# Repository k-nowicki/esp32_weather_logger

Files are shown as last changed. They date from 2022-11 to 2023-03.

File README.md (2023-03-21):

# Weather Station and logger based on ESP32

The Weather Station measures: Temperature, Humidity, Atm. Pressure and Solar exposure. It also keeps track of current date and time and take pictures. All of this data is logged on local storage (i.e. SD card). Main measurements are displayed in real time on the device OLED screen. All current and historical data can also be viewed by the web interface as well as fetched by API.
All user interactions are made by web interface. Besides display and on/off switch, the device has no other way to communicate with user.
The purpose of the device is to deliver historical weather informations along with pictures of those conditions, for further analysis.
Device can be used as weather conditions logger, time-lapse camera or just home weather station.

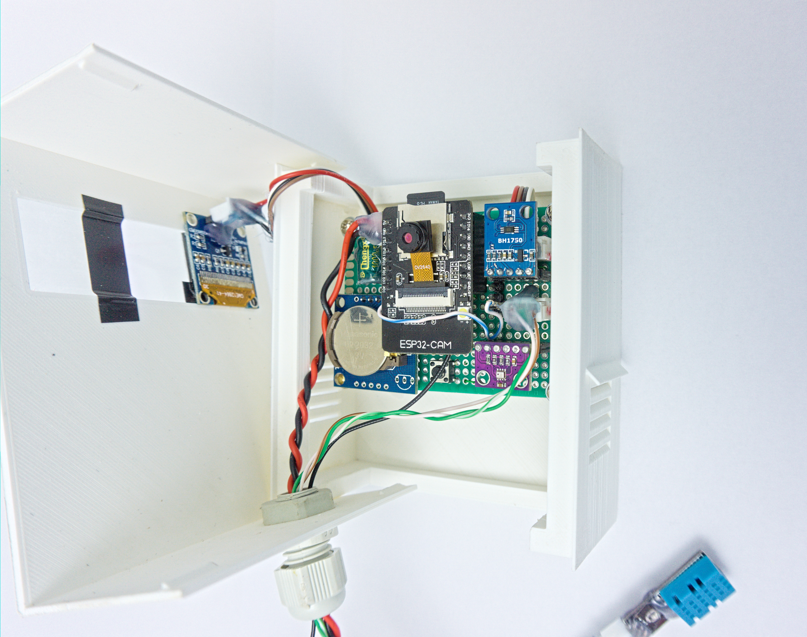
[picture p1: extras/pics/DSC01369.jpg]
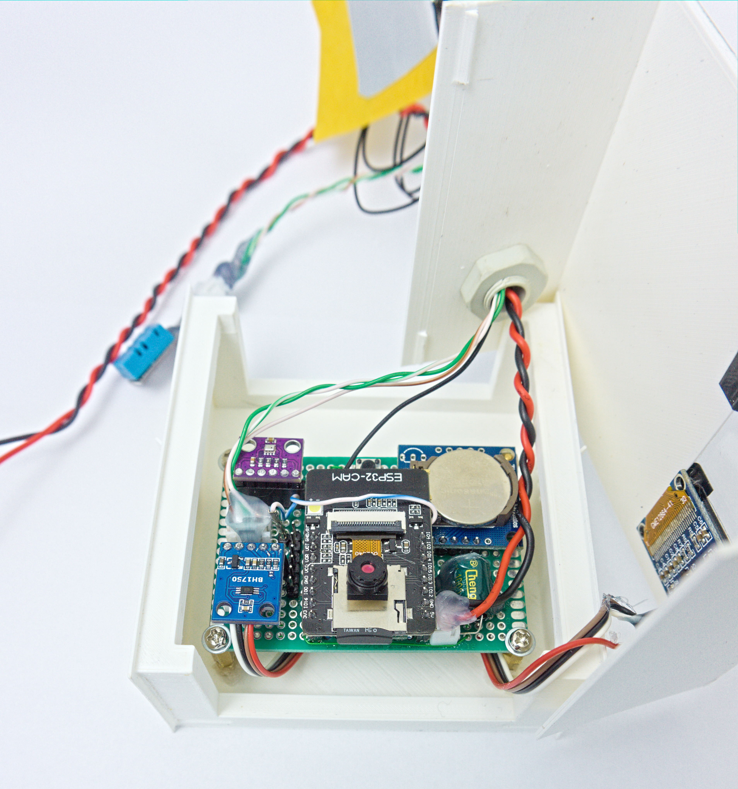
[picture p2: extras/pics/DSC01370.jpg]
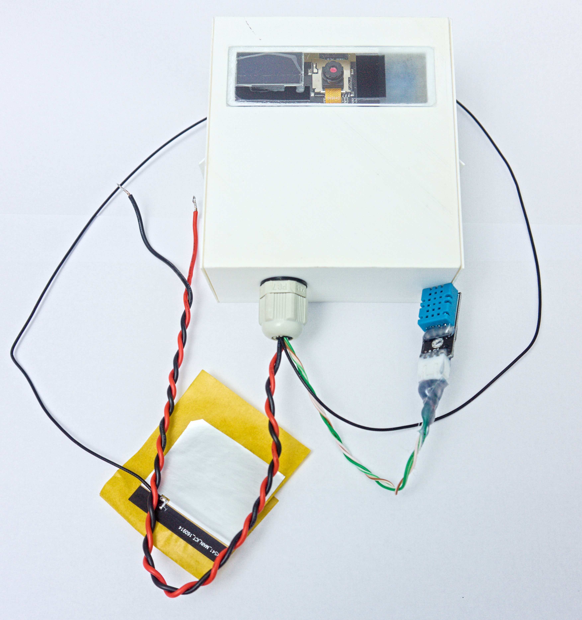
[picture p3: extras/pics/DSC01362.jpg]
  

## Hardware

|  Type | Name/Info  | Libs  |
| --- | --- | --- |
| MCU  | [ESP32-CAM](https://docs.platformio.org/en/latest/boards/espressif32/esp32cam.html)  | [ESP-IDF](https://github.com/espressif/esp-idf)  |
| Humidity/Temperature (VAR 1) | [DHT11](http://gotronik.pl/img/dht11.pdf) | [Anacron-mb/esp32-DHT11](https://github.com/Anacron-mb/esp32-DHT11)  |
| Humidity/Temperature (VAR 2) | [HTU21](https://cdn-shop.adafruit.com/datasheets/1899_HTU21D.pdf) | [Adafruit_HTU21DF](https://github.com/adafruit/Adafruit_HTU21DF_Library)  |
| Pressure/Temperature  |[BMP280](https://www.bosch-sensortec.com/products/environmental-sensors/pressure-sensors/bmp280/)| [Adafruit_BMP280_Library](https://github.com/adafruit/Adafruit_BMP280_Library); [Adafruit_Sensor](https://github.com/adafruit/Adafruit_Sensor); [Adafruit_BusIO](https://github.com/adafruit/Adafruit_BusIO); [arduino-esp32](https://github.com/espressif/arduino-esp32) |
|Light |[BH1750](https://www.handsontec.com/dataspecs/sensor/BH1750%20Light%20Sensor.pdf) |  [claws/BH1750](https://github.com/claws/BH1750); [arduino-esp32](https://github.com/espressif/arduino-esp32)  |
|Wind |[KK-ANEMO]() |  [KK-ANEMO]()|
|OLED |[GME12864-41/ SSD1306](https://nettigo.pl/products/wyswietlacz-oled-0-96-i2c-128x64-ssd1306-bialy) \| [Reserve info](https://datasheethub.com/ssd1306-128x64-mono-0-96-inch-i2c-oled-display/) |[Adafruit_SSD1306](https://github.com/adafruit/Adafruit_SSD1306); [Adafruit-GFX-Library](https://github.com/adafruit/Adafruit-GFX-Library); [arduino-esp32](https://github.com/espressif/arduino-esp32) |
RTC (Var 1)| [HW084 / DS3231](http://www.szhwmake.com/prod_view.aspx?TypeId=83&Id=350&FId=t3:83:3) \| [Reserve info](https://lastminuteengineers.com/ds3231-rtc-arduino-tutorial/) |[ErriezDS3231 (modified)](https://github.com/k-nowicki/ErriezDS3231)|
RTC (Var 2)| [TinyRTC / DS1307](https://www.analog.com/media/en/technical-documentation/data-sheets/DS1307.pdf) \| [Reserve info](https://lastminuteengineers.com/ds1307-rtc-arduino-tutorial/) | [ErriezDS1307 (modified)](https://github.com/Erriez/ErriezDS1307)|
| SD Card  | Any standard SDSC/SDHC/SDXC Card<br/>(preffered at least 8GB for picture storage)  | [ESP-IDF](https://github.com/espressif/esp-idf)  |

## Connections
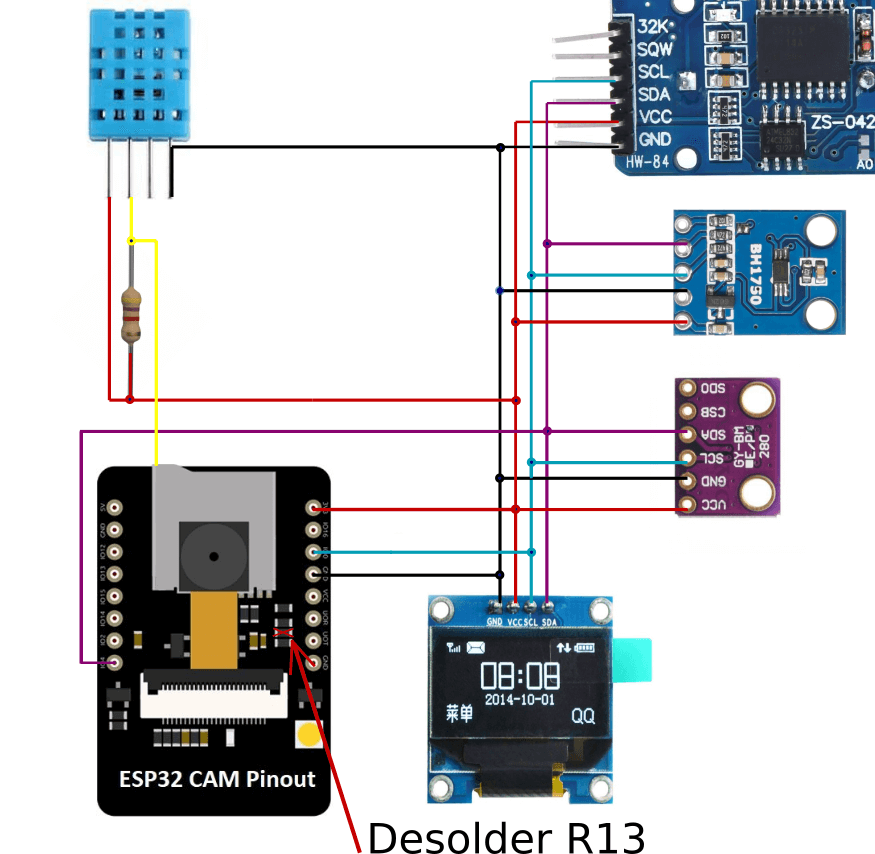
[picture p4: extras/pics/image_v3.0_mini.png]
Wiring diagram


R13 resistor needs to be desoldered (**)

DHT11 sensor needs to be soldered to GPIO33 which is hardwired to onboard LED (*)

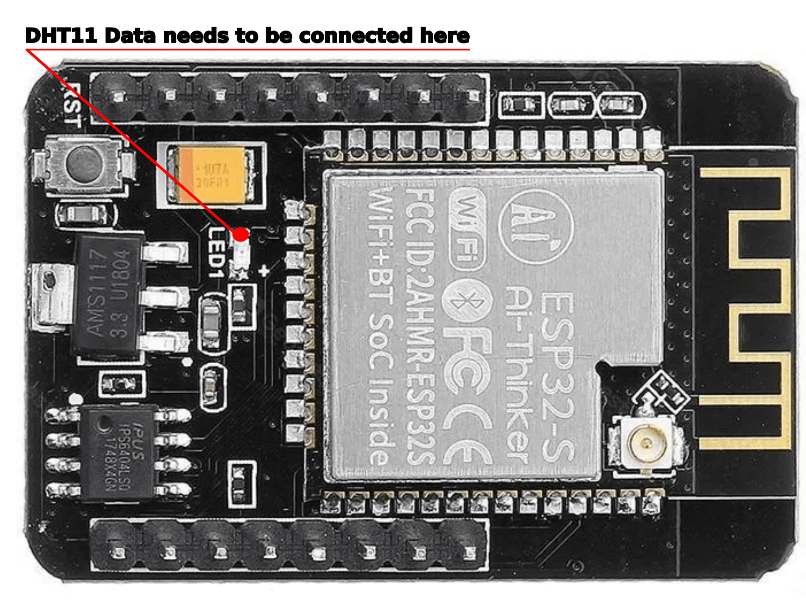
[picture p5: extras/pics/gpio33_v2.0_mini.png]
GPIO33


Warning! On the schematic above SCL and SDA are swapped, you need to change definitions in setup.h or connect them the other way round.

## Environment requirements
This project needs ESP-IDF environment installed on development machine (developed on ESP-IDF v4.4.3).
[Follow the instructions](https://docs.espressif.com/projects/esp-idf/en/v4.4.3/esp32/get-started/index.html "ESP-IDF Framework") to install all necessary software. After installing check your setup first with one of the ESP-IDF examples.

## How to flash your ESP32
Instructions on how to connect and flash esp32 can be found also on [espressif docs](https://docs.espressif.com/projects/esp-idf/en/v3.3.5/get-started-cmake/index.html#step-9-flash-to-a-device "espressiff docs").

## Project status: under development
 
 What is implemented:
  - OLED Display displays current measurements, date, time and IP address
  - Sensors: pressure, temperature from two sensors, humidity, light and wind***
  - External and internal RTCs with periodic NTP time sync
  - WiFi connectivity (with credentials configured by menuconfig)
  - SD card with file system
  - Logging of measurements in json and CSV formatted logs in two densities (1/min -averaged and 1/sec)
  - HTTPS server (serves files from SD and responds to API calls)
  - Camera takes pictures every 5sec. Current picture is displayed on index web page below measurements.
  - Every 5 minutes new picture is saved to SD card
  - Web application for displaying measurements, pictures and logs (with https)
  
  *) DHT11 sensor if used, needs to be connected to GPIO33 which on the board is not connected to any external I/O pin. Instead Adafruit designed the board so that the GPIO33 (which unlike any other available pin has no second function) is connected exclusively to on board LED.

**) I2C_SCL needs to be defined as GPIO4 (There is no other free IO that can be used as I2C signal). But for it to work there is another small hack needed. R13 resistor needs to be desoldered from esp32-cam board. If R13 is not removed, the FLASH_LED driver forces GPIO4 to be max 0.7V and I2C bus will not work.

***) Wind anemometer (KK-ANEMO) connected to I2C bus is also under development. Project will be published soon as open source.

## Assembly and getting ready
Once you have all modules and parts needed as well as software installed:
 - prepare the esp32 board and connect all as shown on the schematic above
 - copy *www* directory with its content to root dir of SD card
 - use menuconfig ( <code>idf.py menuconfig</code> from project root dir) to set:
  - WiFi credentials [KK_Connection_Configuration]
  - RTC type [KK_RTC_Configuration]
 - use setup.h to verify/set:
  - I2C_SDA and I2C_SCL to be consistent with actual connections
  - uncomment definition of used external sensor: <code>EXTERNAL_SENSOR_DHT11</code> or <code>EXTERNAL_SENSOR_HTU21</code>
 - compile the code <code>idf.py build</code>
 - connect the esp32 board to USB and enter flash mode (pull-down GPIO0 and press RESET button)
 - upload flash content and run serial monitor <code>idf.py -p \<COM_PORT> flash monitor</code>  
Replace <code>\<COM_PORT></code> with that in your setup, for example COM4 on Windows or /dev/ttyUSB0 on Linux.
 - after flashing reset your board again, with GPIO0 disconnected from ground this time

If everything done correctly, you should see immediately debug output on the serial monitor.
After several seconds there should be all measurements, date, time and IP address of the station visible on the display.
You can now use this IP to open device web page. Remember that only https protocol works, put <code>https://</code> before IP in your browser! 
It may be also necessary to confirm unsafe access in the browser, as device has no proper third-party certificate installed.

## Housing
As a weather station the device needs to be directly exposed to weather conditions.
I designed enclosure for 3d printing. Files in stl format can be found in extras/case.
Enclosure is designed with 25,4mm x 76,2mm glass window that utilizes standard 1x3 inch microscope slides. 
The best slides are one side matted which works as diffuser for light sensor.

## Web Interface
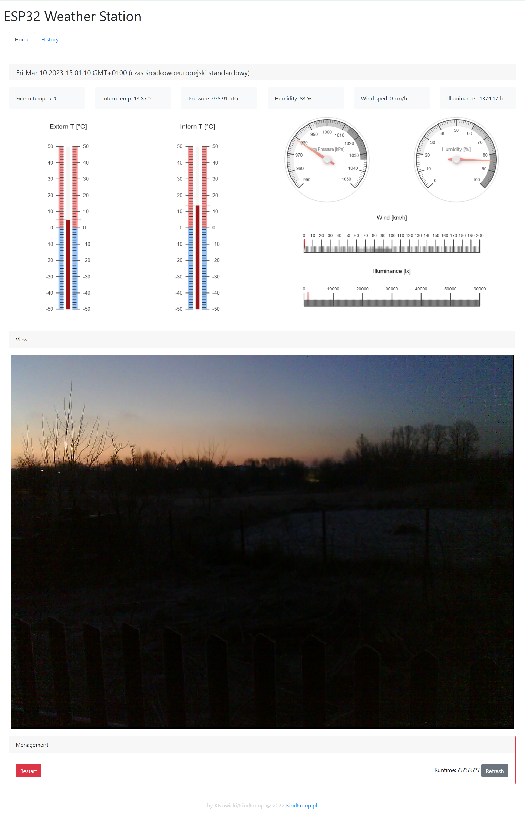
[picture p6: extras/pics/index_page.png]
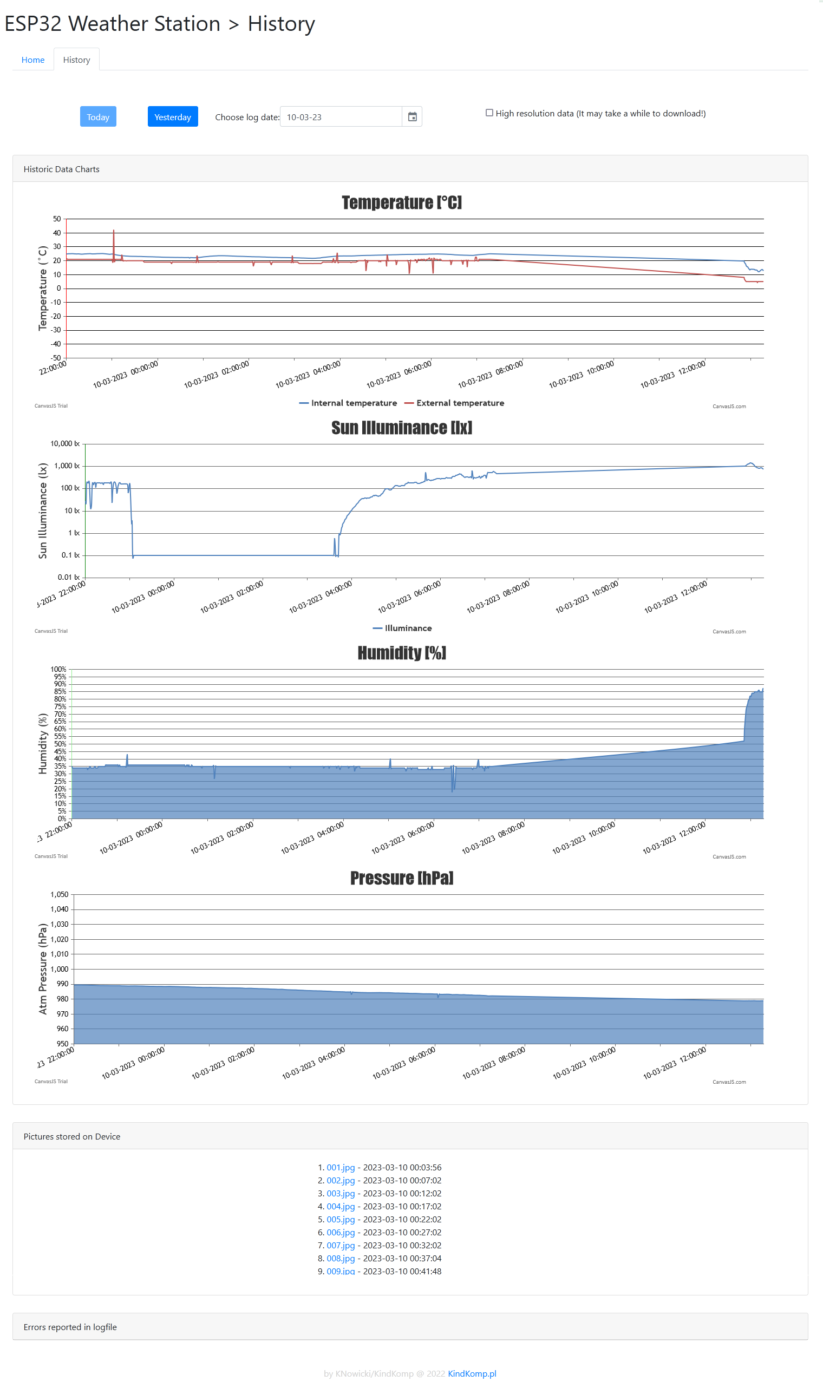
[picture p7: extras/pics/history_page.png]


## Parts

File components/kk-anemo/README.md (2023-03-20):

# KK-ANEMO

## Overview

The KK-Anemometer is a DIY cup-anemometer based on popular A/Y3144 Hall effect 
switch. The Switch is connected to LPC1114 uC, which counts interrupts and measures
wind speed based on that. Communication with that uC is done by I2C bus.
Protocol is extremely simple - send address of the device (0x56) and receive
2-bytes of data. Higher byte is the integer part and lower byte is a fractional 
part. Lower byte needs to be divided by 256 and then added to the integer part to
make whole float value (example below).

<code>
    h_value = __wire_read(); <br/>
    l_value = __wire_read(); <br/>
    velocity = h_value + (float)((l_value*1000)/256)/1000; <br/>
</code>

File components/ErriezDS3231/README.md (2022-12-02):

# DS3231 high precision I2C RTC library for Arduino



This is a DS3231 high precision I2C RTC library for Arduino.

DS3231

## Library features

* libc `<time.h>` compatible
* Read/write date/time `struct tm`
* Set/get Unix epoch UTC `time_t`
* Set/get time (hour, min, sec)
* Set/get date and time (hour, min, sec, mday, mon, year, wday)
* Read temperature (0.25 degree resolution)
* Alarm 1 (second/minute/hour/day/date match) 
* Alarm 2 (minute/hour/day/date match)
* Polling and Alarm `INT/SQW` interrupt pin
* Control `32kHz` out signal (enable/disable)
* Control `SQW` signal (disable / 1 / 1024 / 4096 / 8192Hz)
* Configure aging offset
* Serial terminal interface
* Full RTC register access
* Set date/time over serial with Python script

## Hardware

Any Arduino hardware with a TWI interface and `Wire.h` support.

DS3231 - Arduino UNO

### ESP32 notes

**ESP32 problem:** The Arduino IDE | Board manager installs an old version ```1.0.0``` from `https://dl.espressif.com/dl/package_esp32_index.json` which contains a broken I2C repeated start. Generating a repeated start with ```Wire.endTransmission(false);``` results in reading zero's from any I2C device and is not a problem of this library.

**Solution:** Use the Git master branch (or a newer release when available) to solve this problem as described on:
https://github.com/espressif/arduino-esp32/blob/master/docs/arduino-ide/windows.md.

## Pins

| Pins board - DS3231 | VCC  | GND  | SDA | SCL | SQW |
| --- | :--: | :--: | :---: | :---: | :---: |
| Arduino UNO (ATMega328 boards) |  5V  | GND  | A4 | A5 | D2 (INT0)  |
| Arduino Mega2560 |  5V  | GND  | D20 | D21 | D2 (INT4)  |
| Arduino Leonardo |  5V  | GND  | D2 | D3 | D7 (INT6)  |
| Arduino DUE (ATSAM3X8E) | 3V3  | GND  | 20 | 21 | 2 |
| ESP8266 | 3V3  | GND  | GPIO4 (D2) | GPIO5 (D1) | GPIO0 (D3) |
| ESP32 | 3V3  | GND  | GPIO21 | GPIO22 | GPIO0 |

Note: Tested ESP8266 / ESP32 boards:

* **ESP8266 boards**: ESP12F / WeMos D1 & R2 / Node MCU v2 / v3
* **ESP32 boards:** WeMos LOLIN32 / LOLIN D32

Other unlisted MCU's may work, but are not tested.

## Examples

Arduino IDE | Examples | Erriez DS3231 RTC:

* [AgingOffset](https://github.com/Erriez/ErriezDS3231/blob/master/examples/ErriezDS3231AgingOffset/ErriezDS3231AgingOffset.ino) Aging offset programming
* [AlarmInterrupt](https://github.com/Erriez/ErriezDS3231/blob/master/examples/ErriezDS3231AlarmInterrupt/ErriezDS3231AlarmInterrupt.ino) Alarm with interrupts
* [AlarmPolling](https://github.com/Erriez/ErriezDS3231/blob/master/examples/ErriezDS3231AlarmPolling/ErriezDS3231AlarmPolling.ino) Alarm polled
* [DumpRegisters](https://github.com/Erriez/ErriezDS3231/blob/master/examples/ErriezDS3231DumpRegisters/ErriezDS3231DumpRegisters.ino) Dump registers polled
* [SetBuildDateTime](https://github.com/Erriez/ErriezDS3231/blob/master/examples/ErriezDS3231SetBuildDateTime/ErriezDS3231SetBuildDateTime.ino) Set build date/time
* [SetGetDateTime](https://github.com/Erriez/ErriezDS3231/blob/master/examples/ErriezDS3231SetGetDateTime/ErriezDS3231SetGetDateTime.ino) Simple RTC read date/time example
* [SetGetTime](https://github.com/Erriez/ErriezDS3231/blob/master/examples/ErriezDS3231SetGetTime/ErriezDS3231SetGetTime.ino)  Set/Get time
* [SQWInterrupt](https://github.com/Erriez/ErriezDS3231/blob/master/examples/ErriezDS3231SQWInterrupt/ErriezDS3231SQWInterrupt.ino)  Blink LED on SQW interrupt pin
* [Temperature](https://github.com/Erriez/ErriezDS3231/blob/master/examples/ErriezDS3231Temperature/ErriezDS3231Temperature.ino) Temperature
* [Terminal](https://github.com/Erriez/ErriezDS3231/blob/master/examples/ErriezDS3231Terminal/ErriezDS3231Terminal.ino) Advanced terminal interface with [set date/time Python](https://github.com/Erriez/ErriezDS3231/blob/master/examples/ErriezDS3231Terminal/ErriezDS3231Terminal.py) script
* [Test](https://github.com/Erriez/ErriezDS3231/blob/master/examples/ErriezDS3231Test/ErriezDS3231Test.ino) Regression test
* [WriteRead](https://github.com/Erriez/ErriezDS3231/blob/master/examples/ErriezDS3231WriteRead/ErriezDS3231WriteRead.ino) Write/read `struct tm`

## Documentation

- [Doxygen online HTML](https://erriez.github.io/ErriezDS3231) 
- [Doxygen PDF](https://github.com/Erriez/ErriezDS3231/blob/master/ErriezDS3231.pdf)
- [DS3231 datasheet](https://github.com/Erriez/ErriezDS3231/blob/master/extras/DS3231.pdf)

## Usage

**Initialization**

```c++
#include <Wire.h>
#include <ErriezDS3231.h>

// Create RTC object
ErriezDS3231 rtc;

void setup()
{
    // Initialize TWI with a 100kHz (default) or 400kHz clock
    Wire.begin();
    Wire.setClock(400000);
    
    // Initialize RTC
    while (!rtc.begin()) {
        // Error: Could not detect DS3231 RTC, retry after some time
        delay(3000);
    }
}
```

**Alternative Initialization**

If your platform has more than one I2C buses, You can pass pointer to particular Wire interface to intializer as in example below:

```c++
#include <Wire.h>
#include <ErriezDS3231.h>

// Create RTC object
ErriezDS3231 rtc;

void setup()
{
    // Initialize TWI with a 100kHz (default) or 400kHz clock
    Wire1.begin();
    Wire1.setClock(400000);
    
    // Initialize RTC
    while (!rtc.begin(&Wire1)) {
        // Error: Could not detect DS3231 RTC, retry after some time
        delay(3000);
    }
}
```

**Check oscillator status at startup**

```c++
// Check oscillator status
if (rtc.isOscillatorStopped()) {
    // Error: RTC oscillator stopped. Date/time cannot be trusted. 
    // Set new date/time before reading date/time.

    // Enable oscillator
    rtc.clockEnable(true);
}
```

**Set time**

```c++
// Write time to RTC
if (!rtc.setTime(12, 0, 0)) {
    // Error: Set time failed
}
```

**Get time**

```c++
uint8_t hour;
uint8_t minute;
uint8_t second;

// Read time from RTC
if (!rtc.getTime(&hour, &minute, &second)) {
    // Error: RTC read failed
}
```

**Set date and time**

```c++
// Write RTC date/time: 13:45:09  31 December 2019  0=Sunday, 2=Tuesday
if (!rtc.setDateTime(13, 45, 9,  31, 12, 2019,  2) {
    // Error: RTC write failed
}
```

**Get date and time**

```c++
uint8_t hour;
uint8_t min;
uint8_t sec;
uint8_t mday;
uint8_t mon;
uint16_t year;
uint8_t wday;

// Read RTC date/time
if (!rtc.getDateTime(&hour, &min, &sec, &mday, &mon, &year, &wday) {
    // Error: RTC read failed
}

// hour: 0..23
// min: 0..59
// sec: 0..59
// mday: 1..31
// mon: 1..12
// year: 2000..2099
// wday: 0..6 (0=Sunday .. 6=Saturday)
```

**Write date/time struct tm**

```c++
struct tm dt;

dt.tm_hour = 12;
dt.tm_min = 34;
dt.tm_sec = 56;
dt.tm_mday = 29;
dt.tm_mon = 1; // 0=January
dt.tm_year = 2020-1900;
dt.tm_wday = 6; // 0=Sunday

if (!rtc.write(&dt)) {
    // Error: RTC Read failed
}
```

**Read date/time struct tm**

```c++
struct tm dt;

// Read RTC date/time
if (!rtc.read(&dt)) {
    // Error: RTC read failed
}
```

**Read Unix Epoch UTC**

```c++
time_t t;

// Read Unix epoch UTC from RTC
if (!rtc.getEpoch(&t)) {
    // Error: RTC read failed
}
```

**Write Unix Epoch UTC**

```c++
// Write Unix epoch UTC to RTC
if (!rtc.setEpoch(1599416430UL)) {
    // Error: Set epoch failed
}
```

**Get temperature**

```c++
int8_t temperature = 0;
uint8_t fraction = 0;

// Force temperature conversion
// Without this call, it takes 64 seconds before the temperature is updated.
if (!rtc.startTemperatureConversion()) {
    // Error: Start temperature conversion failed 
}

// Read temperature
if (!rtc.getTemperature(&temperature, &fraction)) {
    // Error: Get temperature failed
}

// Print temperature. The output below is for example: 28.25C
Serial.print(temperature);
Serial.print(F("."));
Serial.print(fraction);
Serial.println(F("C"));
```

**Program Alarm 1**

Note: Alarm 1 and Alarm 2 have different behavior. Please refer to the documentation which ```Alarm1Type``` and ```Alarm2Type``` are supported. Some examples:

```c++
// Generate alarm 1 every second
rtc.setAlarm1(Alarm1EverySecond, 0, 0, 0, 0);

// Generate alarm 1 every minute and second match
rtc.setAlarm1(Alarm1EverySecond, 0, 0, 45, 30);

// Generate alarm 1 every day, hour, minute and second match
rtc.setAlarm1(Alarm1MatchDay, 
              1,  // Alarm day match (1 = Monday)
              12, // Alarm hour match
              45, // Alarm minute match
              30  // Alarm second match
);
```

**Program Alarm 2**

```c++
// Generate alarm 2 every minute
rtc.setAlarm2(Alarm2EveryMinute, 0, 0, 0);

// Generate alarm 2 every hour, minute match
rtc.setAlarm2(Alarm2MatchHours, 0, 23, 59);

// Generate alarm 2 every date, hour, minute match
rtc.setAlarm2(Alarm2MatchDate, 28, 7, 0);
```

**Alarm polling**

Note: The ```INT``` pin changes to low when an Alarm 1 or Alarm 2 match occurs and and the interrupt is enabled. The pin remains low until both alarm flags are cleared by the application.

```c++
// Poll alarm 1 flag
if (rtc.getAlarmFlag(Alarm1)) {
    // Handle Alarm 1
    
    // Clear alarm 1 flag
	rtc.clearAlarmFlag(Alarm1);
}

// Poll alarm 2 flag
if (rtc.getAlarmFlag(Alarm2)) {
    // Handle Alarm 2
    
    // Clear alarm 2 flag
	rtc.clearAlarmFlag(Alarm2);
}
```

**Alarm interrupt**

Note: Enabling interrupt will disable the ```SQW``` output signal.

```c++
// Uno, Nano, Mini, other 328-based: pin D2 (INT0) or D3 (INT1)
#define INT_PIN     2

// Alarm interrupt flag must be volatile
volatile bool alarmInterrupt = false;

#if defined(ARDUINO_ARCH_ESP8266) || defined(ARDUINO_ARCH_ESP32)
ICACHE_RAM_ATTR
#endif
void alarmHandler()
{
    // Set global interrupt flag
    alarmInterrupt = true;
}

void setup()
{
    ...

    // Attach to INT0 interrupt falling edge
    pinMode(INT_PIN, INPUT_PULLUP);
    attachInterrupt(digitalPinToInterrupt(INT_PIN), alarmHandler, FALLING);
    
    // Enable Alarm 1 and 2 interrupts
    rtc.alarmInterruptEnable(Alarm1, true);
    rtc.alarmInterruptEnable(Alarm2, true);
}

void loop()
{
    // Check global alarm interrupt flag
    if (alarmInterrupt) {
        if (rtc.getAlarmFlag(Alarm1)) {
            // Handle alarm 1
            
            // Clear alarm 1 interrupt
            rtc.clearAlarmFlag(Alarm1);
        }
        
        if (rtc.getAlarmFlag(Alarm2)) {
            // Handle alarm 2
            
            // Clear alarm 2 interrupt
            rtc.clearAlarmFlag(Alarm2);
        }
    }
}
```

**32kHz clock out**

Enable or disable ```32kHz``` output pin.

```c++
rtc.outputClockPinEnable(true);  // Enable 
rtc.outputClockPinEnable(false);	// Disable
```

**Square Wave Out (SQW)**

Note: Enabling ```SQW``` pin will disable the alarm ```INT``` signal.

```c++
rtc.setSquareWave(SquareWaveDisable);	// Disable
rtc.setSquareWave(SquareWave1Hz);		// 1Hz
rtc.setSquareWave(SquareWave1024Hz);	// 1024Hz
rtc.setSquareWave(SquareWave4096Hz);	// 4096Hz
rtc.setSquareWave(SquareWave8192Hz);	// 8192Hz
```

## API changes v1.0.1 to v2.0.0

The API has been changed to make RTC libraries compatible with libc `time.h`. This makes it easier
to calculate with date/time and port the application to different platforms. See changes below:

| v1.0.1 | v2.0.0 |
| --- | --- |
| `DS3231_DateTime` | `struct tm` |
| Function returns `true`: failure | Function returns `false`: failure |
| | `clearOscillatorStopFlag()` merged into `oscillatorEnable()` |
| `setDateTime()` | `bool write(struct tm *dt)` |
| `getDateTime()` | `bool read(struct tm *dt)` |
| `getEpochTime()` | `time_t getEpoch()` |
| | `bool setEpoch(time_t t)` |
| | `void setDateTime(uint8_t hour, uint8_t min, uint8_t sec, uint8_t mday, uint8_t mon, uint16_t year, uint8_t wday)` |
| | `void getDateTime(uint8_t *hour, uint8_t *min, uint8_t *sec, uint8_t *mday, uint8_t *mon, uint16_t *year, uint8_t *wday)` |
| `ErriezDS3231Debug` | class removed to reduce flash size |

## Library dependencies

* `Wire.h`
* `Terminal.ino` requires `ErriezSerialTerminal` library.

## Library installation

Please refer to the [Wiki](https://github.com/Erriez/ErriezArduinoLibraries/wiki) page.

## More Arduino Libraries from Erriez

* [Erriez Libraries](https://github.com/Erriez/ErriezArduinoLibraries)

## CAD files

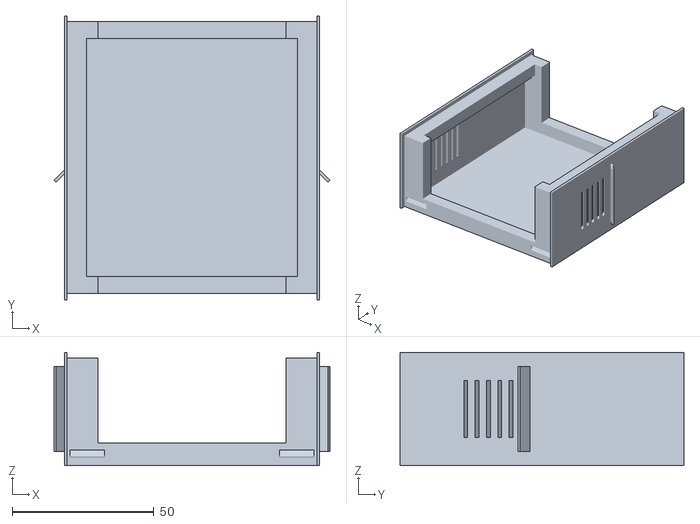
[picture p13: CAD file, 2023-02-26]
extras/case/Base.stl
97.3 x 100.0 x 40.0

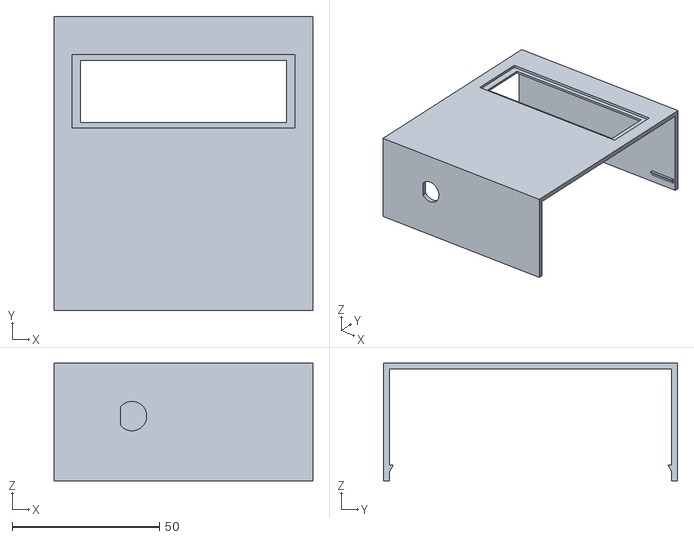
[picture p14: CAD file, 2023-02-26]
extras/case/TopCover.stl
88.0 x 100.0 x 40.0

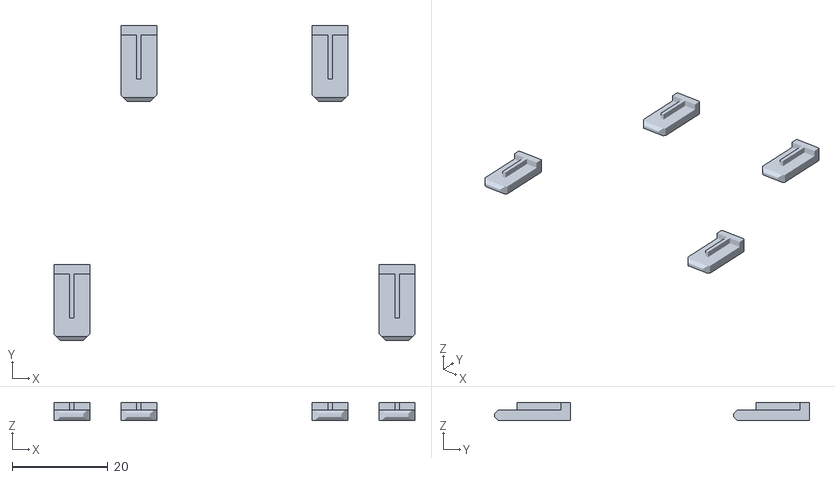
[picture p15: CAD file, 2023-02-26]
extras/case/Mount.stl
75.5 x 66.0 x 3.80

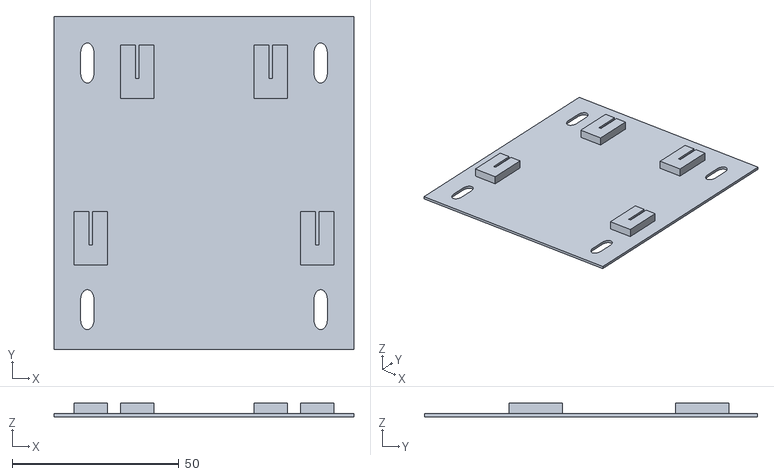
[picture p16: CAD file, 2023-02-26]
extras/case/MountPlate.stl
90.0 x 100.0 x 4.25

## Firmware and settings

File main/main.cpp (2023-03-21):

/* KK Weather Station
 *
 * Platform: ESP32 (Tested on ESP32-CAM Development Board)
 * See project documentation for more detailed description.
 *
 *  Copyright (c) <2022> <Karol Nowicki>
 *
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
 *  THE SOFTWARE IS PROVIDED "AS IS", WITHOUT WARRANTY OF ANY KIND, EXPRESS OR
 *  IMPLIED, INCLUDING BUT NOT LIMITED TO THE WARRANTIES OF MERCHANTABILITY,
 *  FITNESS FOR A PARTICULAR PURPOSE AND NONINFRINGEMENT. IN NO EVENT SHALL THE
 *  AUTHORS OR COPYRIGHT HOLDERS BE LIABLE FOR ANY CLAIM, DAMAGES OR OTHER
 *  LIABILITY, WHETHER IN AN ACTION OF CONTRACT, TORT OR OTHERWISE, ARISING FROM,
 *  OUT OF OR IN CONNECTION WITH THE SOFTWARE OR THE USE OR OTHER DEALINGS IN THE
 *  SOFTWARE.
*/

//System
#include <stdio.h>
#include <stdlib.h>
#include <string.h>
#include <sys/unistd.h>
#include <sys/stat.h>
#include "freertos/FreeRTOS.h"
#include "freertos/task.h"
#include "freertos/semphr.h"
#include <Wire.h>
#include "esp_system.h"
#include "esp_log.h"
#include "esp_err.h"
#include "esp_event.h"
#include "esp_attr.h"
#include "esp_sleep.h"
#include "esp_sntp.h"
#include <time.h>
#include "nvs_flash.h"
#include "esp_vfs_fat.h"
#include "sdmmc_cmd.h"
#include "driver/sdmmc_host.h"
#include <protocol_common.h>
#include <k_math.h>

//App
#include "setup.h"
#include "tasks/tasks.h"
#include "app.h"
#include "kk_http_app/src/kk_http_app.h"
#include "kk_http_app/src/kk_http_server_setup.h"
#include "camera_helper.h"

extern "C" {
  void app_main(void);
}



/*******************************************************************************
 * Variable definitions
 */

//Business logic global variables
measurement g_curr_measures; // Current measurements

// RTC object depending on used physical device
#ifdef CONFIG_RTC_DS1307
ErriezDS1307 g_rtc;
#elif CONFIG_RTC_DS3231
ErriezDS3231 g_rtc;
#endif

//Sensor global objects
BH1750 g_lightMeter(BH1750_ADDR);
ANEMO g_windMeter(ANEMO_ADDR);
Adafruit_BMP280 g_pressureMeter(&Wire1); // I2C
Adafruit_SSD1306 g_display(SCREEN_WIDTH, SCREEN_HEIGHT, &Wire1, OLED_RESET);
#ifdef EXTERNAL_SENSOR_HTU21
Adafruit_HTU21DF g_htu21 = Adafruit_HTU21DF();
#endif

//SD Card global object
sdmmc_card_t * g_card;

//semaphores
SemaphoreHandle_t g_current_measuers_mutex;
SemaphoreHandle_t g_uart_mutex;
SemaphoreHandle_t g_card_mutex;

//task handlers
TaskHandle_t g_vRTCTaskHandle = NULL;
TaskHandle_t g_vDHT11TaskHandle = NULL;
TaskHandle_t g_vSensorsTaskHandle = NULL;
TaskHandle_t g_vDisplayTaskHandle = NULL;
TaskHandle_t g_vCameraTaskHandle = NULL;
TaskHandle_t g_vSDCSVLGTaskHandle = NULL;
TaskHandle_t g_vSDAVGLGTaskHandle = NULL;
TaskHandle_t g_vSDJSLGTaskHandle = NULL;
TaskHandle_t g_vStatsTaskHandle = NULL;

/*******************************************************************************
 *  App Main
 */
void app_main(void){
  const char* TAG = "app_setup";
  //create semaphores
  g_current_measuers_mutex = xSemaphoreCreateMutex();
  g_uart_mutex = xSemaphoreCreateMutex();
  g_card_mutex = xSemaphoreCreateMutex();
  if(g_uart_mutex == NULL){
      ESP_LOGE(TAG, "UART Mutex creation failed! Hold till reset!");
      for(;;);
  }

  //initArduino();
  //Allow other core to finish initialization
  vTaskDelay(pdMS_TO_TICKS(10));

  //Setup Camera
  if(init_camera(FRAMESIZE) != ESP_OK){
    ESP_LOGE(TAG, "Camera initialization failed!");
//    for(;;); // Don't proceed, loop forever
  }else{
    ESP_LOGI(TAG, "Camera initialized.");
  }

  //Set I2C interface
  Wire1.begin(I2C_SDA, I2C_SCL);
  Wire1.setClock(400000);

  //Setup OLED display
  if(!g_display.begin(SSD1306_SWITCHCAPVCC, OLED_ADDR)) {
    g_display.display();
    ESP_LOGE(TAG, "SSD1306 allocation failed");
  }else{
    ESP_LOGI(TAG, "SSD1306 OLED Display initialized.");
    init_app_screen();
  }

  //search_i2c(); // search for I2C devices (helpful if any uncertainty about sensor addresses raised)

  //Set GPIOS for DHT11 and DS18B20 as GPIOs
  ESP_LOGI(TAG, "GPIO's configuration...");
  PIN_FUNC_SELECT(GPIO_PIN_MUX_REG[GPIO_DHT11], PIN_FUNC_GPIO);
  PIN_FUNC_SELECT(GPIO_PIN_MUX_REG[GPIO_DS18B20], PIN_FUNC_GPIO);
  //Set up DHT11 GPIO
  DHT11_init(GPIO_DHT11);
  ESP_LOGI(TAG, "GPIO's initialized!");


  //BH1750 Initialization
  if(!g_lightMeter.begin(BH1750::Mode::CONTINUOUS_HIGH_RES_MODE, BH1750_ADDR, &Wire1)){
    ESP_LOGE(TAG, "BH1750 initialization failed!");
    for(;;); // Don't proceed, loop forever
  }else{
    ESP_LOGI(TAG, "BH1750 Light meter initialized.");
  }

  //KK-ANEMO Initialization
  if(!g_windMeter.begin(ANEMO_ADDR, &Wire1)){
    ESP_LOGE(TAG, "ANEMOMETER initialization failed!");
    for(;;); // Don't proceed, loop forever
  }else{
    ESP_LOGI(TAG, "ANEMOMETER initialized.");
  }

  //BMP280 Initialization
  if(!g_pressureMeter.begin(BMP280_ADDR)){
    ESP_LOGE(TAG, "BMP280 initialization failed!");
    //for(;;); // Don't proceed, loop forever
  }else{
    ESP_LOGI(TAG, "BMP280 Pressure meter initialized.");
  }

  #ifdef EXTERNAL_SENSOR_HTU21
  //HTU21 Initialization
  if(!g_htu21.begin(&Wire1)){
    ESP_LOGE(TAG, "HTU21 initialization failed!");
    //for(;;); // Don't proceed, loop forever
  }else{
    ESP_LOGI(TAG, "HTU21 Pressure meter initialized.");
  }
  #endif

  //RTC Initialization
  if(!g_rtc.begin(&Wire1)){
    ESP_LOGE(TAG, "RTC DS3231 initialization failed!");
    for(;;); // Don't proceed, loop forever
  }else{
    ESP_LOGI(TAG, "DS3231 Real Time Clock initialized.");
  }

  //SD Card initialization
  if(init_sd() != ESP_OK){
    ESP_LOGE(TAG, "Cannot initialize SD Card!");
    for(;;); // Don't proceed, loop forever
  }

  //WiFi Initialization
  ESP_LOGI(TAG, "Initializing NVS flash...");
  ESP_ERROR_CHECK( nvs_flash_init() );
  ESP_LOGI(TAG, "Initializing network interface...");
  ESP_ERROR_CHECK(esp_netif_init());
  ESP_ERROR_CHECK( esp_event_loop_create_default() );
  ESP_LOGI(TAG, "Initializing http(s) server...");
  setup_httpd();
  ESP_LOGI(TAG, "Connecting to WiFi network...");
  ESP_ERROR_CHECK(network_connect());

  //DS18B20 Initialization
  //initialize_ds18b20();

  //Create business tasks:
  xTaskCreatePinnedToCore( vRTCTask, "RTC", 3096, NULL, RTC_TASK_PRIO, &g_vRTCTaskHandle, tskNO_AFFINITY );
  xTaskCreatePinnedToCore( vDHT11Task, "DHT11", 2048, NULL, SENSORS_TASK_PRIO, &g_vDHT11TaskHandle, tskNO_AFFINITY );
  xTaskCreatePinnedToCore( vSensorsTask, "SENS", 2048, NULL, SENSORS_TASK_PRIO, &g_vSensorsTaskHandle, tskNO_AFFINITY );
  xTaskCreatePinnedToCore( vDisplayTask, "OLED", 2048, NULL, DISPLAY_TASK_PRIO, &g_vDisplayTaskHandle, tskNO_AFFINITY );
  xTaskCreatePinnedToCore( vCameraTask, "CAM", 48*1024, NULL, CAM_TASK_PRIO, &g_vCameraTaskHandle, tskNO_AFFINITY );
  //Loggers
  xTaskCreatePinnedToCore( vSDCSVLGTask, "SDCSVLG", 6*1024, NULL, SDCSVLG_TASK_PRIO, &g_vSDCSVLGTaskHandle, tskNO_AFFINITY );
//  xTaskCreatePinnedToCore( vSDJSLGTask, "SDJSLG", 6*1024, NULL, SDJSLG_TASK_PRIO, &g_vSDJSLGTaskHandle, tskNO_AFFINITY );
  xTaskCreatePinnedToCore( vSDAVGLGTask, "SDAVGLG", 6*1024, NULL, SDAVGLG_TASK_PRIO, &g_vSDAVGLGTaskHandle, tskNO_AFFINITY );
  //Create and start stats task
  xTaskCreatePinnedToCore(vStatsTask, "STATS", 3072, NULL, STATS_TASK_PRIO, &g_vStatsTaskHandle, tskNO_AFFINITY);

}

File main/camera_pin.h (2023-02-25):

/*
 * camera_pin.h
 *
 *  Created on: 22 lut 2023
 *      Author: Karol
 */

#ifndef MAIN_CAMERA_PIN_H_
#define MAIN_CAMERA_PIN_H_

// Freenove ESP32-WROVER CAM Board PIN Map
#if CONFIG_BOARD_WROVER_KIT
#define CAM_PIN_PWDN -1  //power down is not used
#define CAM_PIN_RESET -1 //software reset will be performed
#define CAM_PIN_XCLK 21
#define CAM_PIN_SIOD 26
#define CAM_PIN_SIOC 27

#define CAM_PIN_D7 35
#define CAM_PIN_D6 34
#define CAM_PIN_D5 39
#define CAM_PIN_D4 36
#define CAM_PIN_D3 19
#define CAM_PIN_D2 18
#define CAM_PIN_D1 5
#define CAM_PIN_D0 4
#define CAM_PIN_VSYNC 25
#define CAM_PIN_HREF 23
#define CAM_PIN_PCLK 22
#endif

// ESP-EYE PIN Map
#if CONFIG_BOARD_CAMERA_MODEL_ESP_EYE
#define PWDN_GPIO_NUM    -1
#define RESET_GPIO_NUM   -1
#define XCLK_GPIO_NUM    4
#define SIOD_GPIO_NUM    18
#define SIOC_GPIO_NUM    23

#define Y9_GPIO_NUM      36
#define Y8_GPIO_NUM      37
#define Y7_GPIO_NUM      38
#define Y6_GPIO_NUM      39
#define Y5_GPIO_NUM      35
#define Y4_GPIO_NUM      14
#define Y3_GPIO_NUM      13
#define Y2_GPIO_NUM      34
#define VSYNC_GPIO_NUM   5
#define HREF_GPIO_NUM    27
#define PCLK_GPIO_NUM    25
#endif


// AiThinker ESP32Cam PIN Map
#if CONFIG_BOARD_ESP32CAM_AITHINKER
#define CAM_PIN_PWDN 32
#define CAM_PIN_RESET -1 //software reset will be performed
#define CAM_PIN_XCLK 0
#define CAM_PIN_SIOD 26
#define CAM_PIN_SIOC 27

#define CAM_PIN_D7 35
#define CAM_PIN_D6 34
#define CAM_PIN_D5 39
#define CAM_PIN_D4 36
#define CAM_PIN_D3 21
#define CAM_PIN_D2 19
#define CAM_PIN_D1 18
#define CAM_PIN_D0 5
#define CAM_PIN_VSYNC 25
#define CAM_PIN_HREF 23
#define CAM_PIN_PCLK 22
#endif



// TTGO T-Journal ESP32 Camera PIN Map
#if CONFIG_BOARD_CAMERA_MODEL_TTGO_T_JOURNAL
#define PWDN_GPIO_NUM      0
#define RESET_GPIO_NUM    15
#define XCLK_GPIO_NUM     27
#define SIOD_GPIO_NUM     25
#define SIOC_GPIO_NUM     23

#define Y9_GPIO_NUM       19
#define Y8_GPIO_NUM       36
#define Y7_GPIO_NUM       18
#define Y6_GPIO_NUM       39
#define Y5_GPIO_NUM        5
#define Y4_GPIO_NUM       34
#define Y3_GPIO_NUM       35
#define Y2_GPIO_NUM       17
#define VSYNC_GPIO_NUM    22
#define HREF_GPIO_NUM     26
#define PCLK_GPIO_NUM     21
#endif



#endif /* MAIN_CAMERA_PIN_H_ */

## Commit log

2022-11-27 Transformed to cpp; Adafruit SSD1306 and GFX libs added as component; ESP-IDF Arduino libs added as component; Display test works
2022-11-28 DHT11 added, not working yet. OLED Display: display.print functions not working
    [main.cpp]
2022-11-28 Adafruit GFX lib switched to original, Adafruit Bus IO lib added. Display works with print functions
2022-11-28 DHT11 sensor works
2022-11-28 BH1750 Light sensor added, working
2022-11-28 BMP280 Sensor added. DHT11Task prints all measured env parameters once every second to UART.
2022-11-30 Setup directives moved to setup.h; App level declarations moved to app.h; Menuconfig fixes (ISP eeprom size, deprecated include headers); Measurements combined in global struct curr_measures; Writing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
    [app.h, main.cpp, setup.h]
2022-11-30 All periodic info printed to UART dbg moved to stats task; DHT11 measurement schedule improved; Faster measures and updates on display;
2022-12-02 ErriezDS3231 modified lib added. Simple RTC task added to test RTC communication. Readme updated.
    [DS3231_Arduino_UNO.fzz]
2022-12-02 General dbg info printfs changed to LOGs; System time logged right after external RTC time
2022-12-06 Display init moved earlier in initialization process; some text fixes
    [main.cpp, vRTCTask.cpp]
2022-12-08 SD and file system initialization moved to app setup; SD/FS initialization helpers moved to app_global_helper.cpp; SD file list printed to uart ritght after Logging task start; SD_MOUNTPOINT, SD_MAX_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
2022-12-09 SD Card Task removed; Logging Task added; Logging to json format works; Missing signal from rtc task to change log file at the end of day; Besides that all works
    [main.cpp, setup.h]
2022-12-10 Logging starts after notification from RTC that time is updated; Date change detection for logging file renaming; sdkconfig: halt on panic option restored, increased number of filesystem mountpoints;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
2022-12-10 Log file renaming fixed; cleanup;
    [app.h, vRTCTask.cpp]
2022-12-10 Wiring diagram update; readme update
2022-12-11 SDLogT: SD card reinitialization on failure
    [app.h, app_global_helper.cpp, main.cpp]
2022-12-14 HTTP server: File serving from /sd/www dir; data serving for /data/* uris; dir kk_http_app moved from components to main/ as it is part of app and needs app level methods/variables access; IDF-Arduin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
    [app.h, main.cpp]
2022-12-14 HTTP server: workarounds for arduino lib compatibility (BIN definitions)
    [main.cpp]
2022-12-16 http server: /data/current_ms.json path handled, fixed memory leak, CORS header added for external development of the web interface
2022-12-20 Another task logging averaged values (over 1 minute) to separate logfile added. WebApp now takes those 1-minute resolution logs for displaying historical charts. Full resolution logs can still be dow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
    [app.h, app_global_helper.cpp, main.cpp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]
2022-12-20 WebApp: Historic charts improved; Added date picker; Added High/Low resolution checkbox; Two index buttons left: for today and yesterday logs
2023-02-17 DS1307 RTC driver added along with RTC selection directive
2023-02-21 Camera driver added (esp32-camera by espressif)
2023-02-22 Camera helper and setup added;
2023-02-25 Modified I2C pins for sensors -IO4 replaced IO0 as IO0 is used for camera xclk (needs hardware hacking again - remove R13); Camera takes 1 pic every 5sec. Picture is displayed on index webpage
    [partitions.csv]
2023-02-26 Camera task finished; Pictures are stored in /dcim/ as NNN_DDMMYYY.jpg; Current View is stored in dcim/0/current.jpg; Pictures are stored every 5min, current view is refreshed every 5sec; Long File N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
2023-02-26 Case stl files added
    [Base.stl, Mount.stl, MountPlate.stl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]
2023-02-26 Readme and schematic updated; Housing stl files added
2023-02-28 Clear internal queue part of camera_capture() removed as it basically takes one more photo for nothing;
2023-03-05 ESP-IDF Updated to v4.4.4; Task priorities changed; Remote RESTART (by http request) forced to work by WDT; WebApp files modified to display reset page; Global accessible task handlers added for each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
    [cam_hal.c, camera_helper.cpp, main.cpp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]
2023-03-05 Pictures are stored only if light is >0.5lux; Current image on index page refresh rate changed to 4999ms
2023-03-10 Camera parameters and setup tweaked to resolve issues with high entropy images not having EOIs; Tasks timings optimization
    [app.h, app_global_helper.cpp, cam_hal.c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]
2023-03-10 Readme update; Prototype pictures added
2023-03-20 Added wind measurement with kk-anemometer (with new kk-anemo lib); Resolved issues with messed dbg output from different tasks by mutex on dbg uart; Resolved issue with NAN values from adafruit senso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
    [app.h, kk-anemo.cpp, main.cpp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]
2023-03-21 Readings stability improved by not passing read errors; OLED display info layout changed - Wind display added
    [kk-anemo.cpp]
2023-03-21 HTU21 Humidity and temperature I2C sensor added in place of DHT11; It is still possible to use DHT11 by replaceing defined EXTERNAL_SENSOR in setup.h
    [app.h, app_global_helper.cpp, main.cpp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]
2023-03-21 HTU21 sensor and wind anemometer Readme update
